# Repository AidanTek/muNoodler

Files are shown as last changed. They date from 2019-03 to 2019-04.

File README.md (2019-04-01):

# µNoodler Project
## Technical Files and Info for the µNoodler SAMD21G18A breakout

This project is for me to learn about a number of things, the idea being to build a SAMD21G18A MCU breakout from the ground up that can be used for Circuit Python, MicroPython or Arduino programming. You are welcome to use the files here for anything you want. 

This project was and is possible because of the amazing contributions towards OSH from Adafruit and Arduino - in support, please buy genuine products from these companies!

This is a work in progress! Aidan Taylor 2019

See the installation guide if you have a muNoodler board to experiment with. The Sketch directory provides code examples - contributions are welcome!

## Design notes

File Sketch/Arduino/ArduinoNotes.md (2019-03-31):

# Notes on using the Arduino IDE with the µNoodler

## Native Usb

To send data over serial back to a computer, use the SerialUSB object in place of Serial. For example:

```cpp
SerialUSB.begin(115200);
SerialUSB.println("Hello World!");
```

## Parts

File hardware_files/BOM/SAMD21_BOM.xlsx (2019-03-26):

Qty | Value | Device | Package | Parts | Description | AVAILABILITY | DESCRIPTION | MF | MP | PACKAGE | PRICE | PROD_ID | SPICEPREFIX | VALUE
1 |  | CONN_08";1X08" | J1 | Multi connection point. Often used as Generic Header-pin footprint for 0.1 inch spaced/style header connections |  |  |  |  |  |  | CONN-08438
2 |  | LED0603 | LED-0603 | D1, D2 | LED (Generic)
2 |  | R-EU_R0603 | R0603 | R1, R2 | RESISTOR, European symbol |  |  |  |  |  |  |  | R
4 | 0.1uf | C-EUC0603 | C0603 | C3, C4, C5, C7 | CAPACITOR, European symbol |  |  |  |  |  |  |  | C
1 | 10118193-0001LF | 10118193-0001LF | FCI_10118193-0001LF | P1 | Micro USB B Type Receptacle | Unavailable | Conn Micro USB Type B RCP 5 POS 0.65mm Solder RA SMD 5 Terminal 1 Port T/R | Amphenol FCI | 10118193-0001LF | None | None
2 | 10uf | C-EUC0805 | C0805 | C2, C8 | CAPACITOR, European symbol |  |  |  |  |  |  |  | C
1 | 120 | FERRITE_BEAD-0603 | 603 | FB1 | Ferrite Bead (blocks, cores, rings, chokes, etc.) |  |  |  |  |  |  | NDUC-13805 |  | 30Œ©/1.8A
2 | 15pf | C-EUC0603 | C0603 | C9, C10 | CAPACITOR, European symbol |  |  |  |  |  |  |  | C
2 | 1uf | C-EUC0805 | C0805 | C1, C6 | CAPACITOR, European symbol |  |  |  |  |  |  |  | C
1 | 32.768kHz | CRYSTAL-32.768KHZSMD-3.2X1.5 | CRYSTAL-SMD-3.2X1.5MM | Y1 | 32.768kHz Crystal |  |  |  |  |  |  | XTAL-13062 |  | 32.768kHz
1 | ATSAMD21G-A | ATSAMD21G-A | TQFP-48 | U1 | Atmel SAMD21G SMART ARM-Based Microcontroller |  |  |  |  |  |  | IC-13064
2 | HEADER_16X1 | HEADER_16X1 | HDRV16W64P254_1X16_4064X254X900B_NO_SILK | U$1, U$2
1 | KXT3_LOWPROFILE_SMDSWITCH | KXT3_LOWPROFILE_SMDSWITCH | KXT3_SMD_SWITCH | SW1
1 | TLV1117LV33DCYT | TLV1117LV33DCYT | SOT223 | REG1

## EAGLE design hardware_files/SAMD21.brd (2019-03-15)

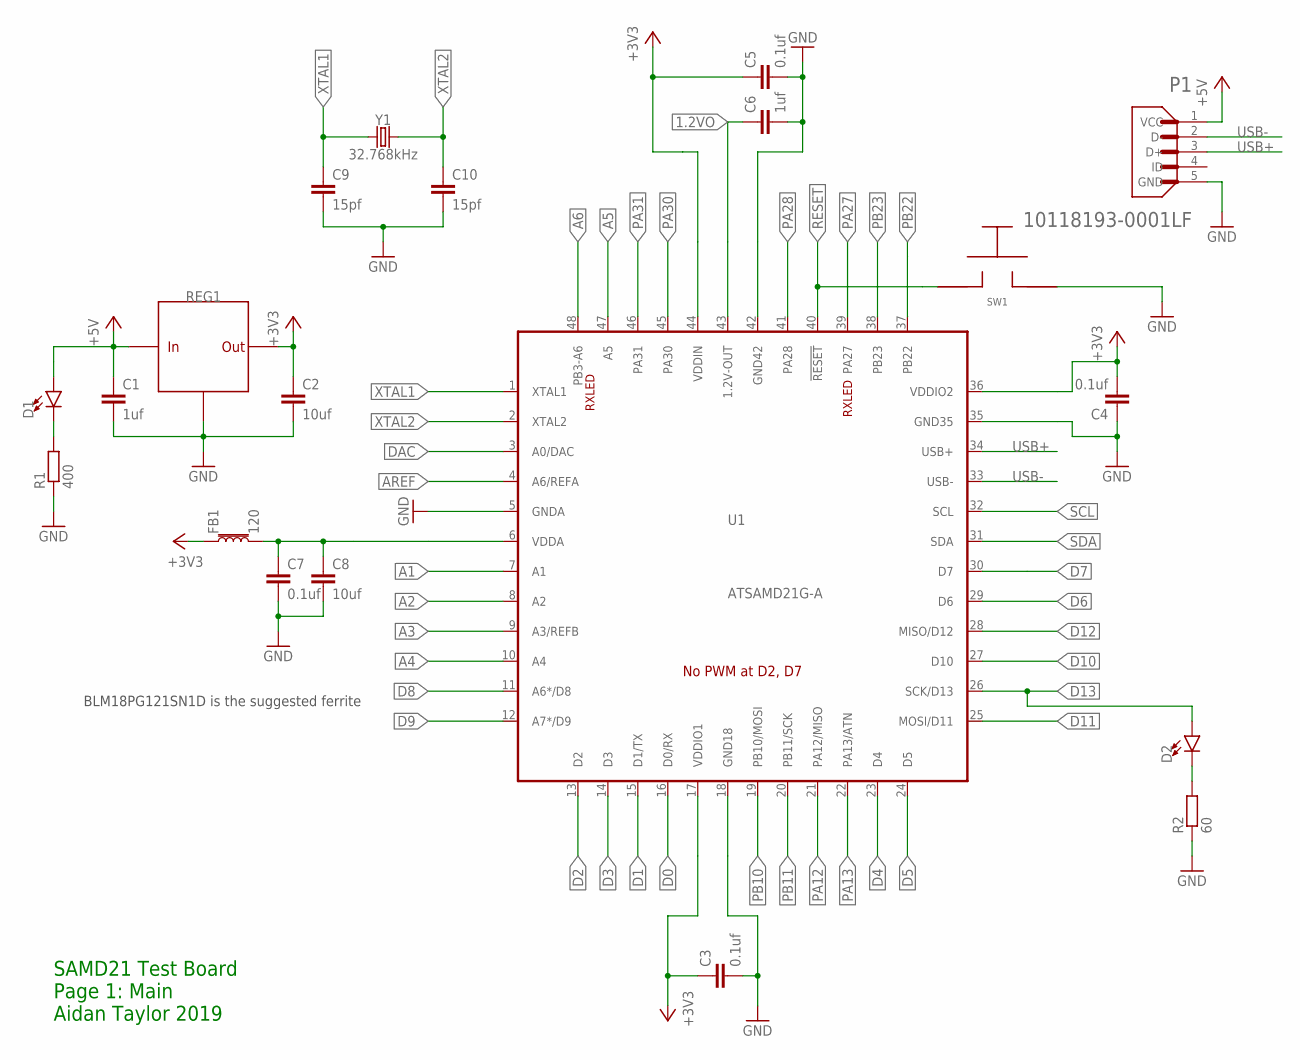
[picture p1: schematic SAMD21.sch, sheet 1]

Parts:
C1, C6: 1uf; C0805
C2, C8: 10uf; C0805
C3, C4, C5, C7: 0.1uf; C0603
C9, C10: 15pf; C0603
D1, D2: LED0603; LED-0603
FB1: 120; 0603
P1: 10118193-0001LF; FCI_10118193-0001LF
R1: 400; R0603
R2: 60; R0603
REG1: TLV1117LV33DCYT; SOT223
SW1: KXT3_LOWPROFILE_SMDSWITCH; KXT3_SMD_SWITCH
U1: ATSAMD21G-A; TQFP-48
Y1: 32.768kHz; CRYSTAL-SMD-3.2X1.5MM

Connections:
1.2VO: C6.1, U1.43 (1.2V-OUT); also elsewhere on the board
+3V3: C2.1, C3.1, C4.2, C5.1, FB1.1, REG1.2 (VOUT), REG1.4 (VOUT), U1.17 (VDDIO1), U1.36 (VDDIO2), U1.44 (VDDIN); also elsewhere on the board
+5V: C1.1, D1.A, P1.1 (VCC), REG1.3 (VIN); also elsewhere on the board
A1: U1.7 (A1); also elsewhere on the board
A2: U1.8 (A2); also elsewhere on the board
A3: U1.9 (A3/REFB); also elsewhere on the board
A4: U1.10 (A4); also elsewhere on the board
A5: U1.47 (A5); also elsewhere on the board
A6: U1.48 (PB3-A6); also elsewhere on the board
AREF: U1.4 (A6/REFA); also elsewhere on the board
D0: U1.16 (D0/RX); also elsewhere on the board
D1: U1.15 (D1/TX); also elsewhere on the board
D2: U1.13 (D2); also elsewhere on the board
D3: U1.14 (D3); also elsewhere on the board
D4: U1.23 (D4); also elsewhere on the board
D5: U1.24 (D5); also elsewhere on the board
D6: U1.29 (D6); also elsewhere on the board
D7: U1.30 (D7); also elsewhere on the board
D8: U1.11 (A6*/D8); also elsewhere on the board
D9: U1.12 (A7*/D9); also elsewhere on the board
D10: U1.27 (D10); also elsewhere on the board
D11: U1.25 (MOSI/D11); also elsewhere on the board
D12: U1.28 (MISO/D12); also elsewhere on the board
D13: D2.A, U1.26 (SCK/D13); also elsewhere on the board
DAC: U1.3 (A0/DAC); also elsewhere on the board
GND: C1.2, C2.2, C3.2, C4.1, C5.2, C6.2, C7.2, C8.2, C9.2, C10.2, P1.5 (GND), R1.1, R2.1, REG1.1 (GND), SW1.P$2, U1.5 (GNDA), U1.18 (GND18), U1.35 (GND35), U1.42 (GND42); also elsewhere on the board
unnamed: C7.1, C8.1, FB1.2, U1.6 (VDDA)
unnamed: D1.C, R1.2
unnamed: D2.C, R2.2
PA12: U1.21 (PA12/MISO); also elsewhere on the board
PA13: U1.22 (PA13/ATN); also elsewhere on the board
PA27: U1.39 (PA27)
PA28: U1.41 (PA28)
PA30: U1.45 (PA30); also elsewhere on the board
PA31: U1.46 (PA31); also elsewhere on the board
PB10: U1.19 (PB10/MOSI); also elsewhere on the board
PB11: U1.20 (PB11/SCK); also elsewhere on the board
PB22: U1.37 (PB22); also elsewhere on the board
PB23: U1.38 (PB23); also elsewhere on the board
RESET: SW1.P$1, U1.40 (!RESET!); also elsewhere on the board
SCL: U1.32 (SCL); also elsewhere on the board
SDA: U1.31 (SDA); also elsewhere on the board
USB+: P1.3 (D+), U1.34 (USB+)
USB-: P1.2 (D-), U1.33 (USB-)
XTAL1: C9.1, U1.1 (XTAL1), Y1.P$1 (1)
XTAL2: C10.1, U1.2 (XTAL2), Y1.P$2 (2)

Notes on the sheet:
BLM18PG121SN1D is the suggested ferrite
SAMD21 Test Board Page 1: Main Aidan Taylor 2019

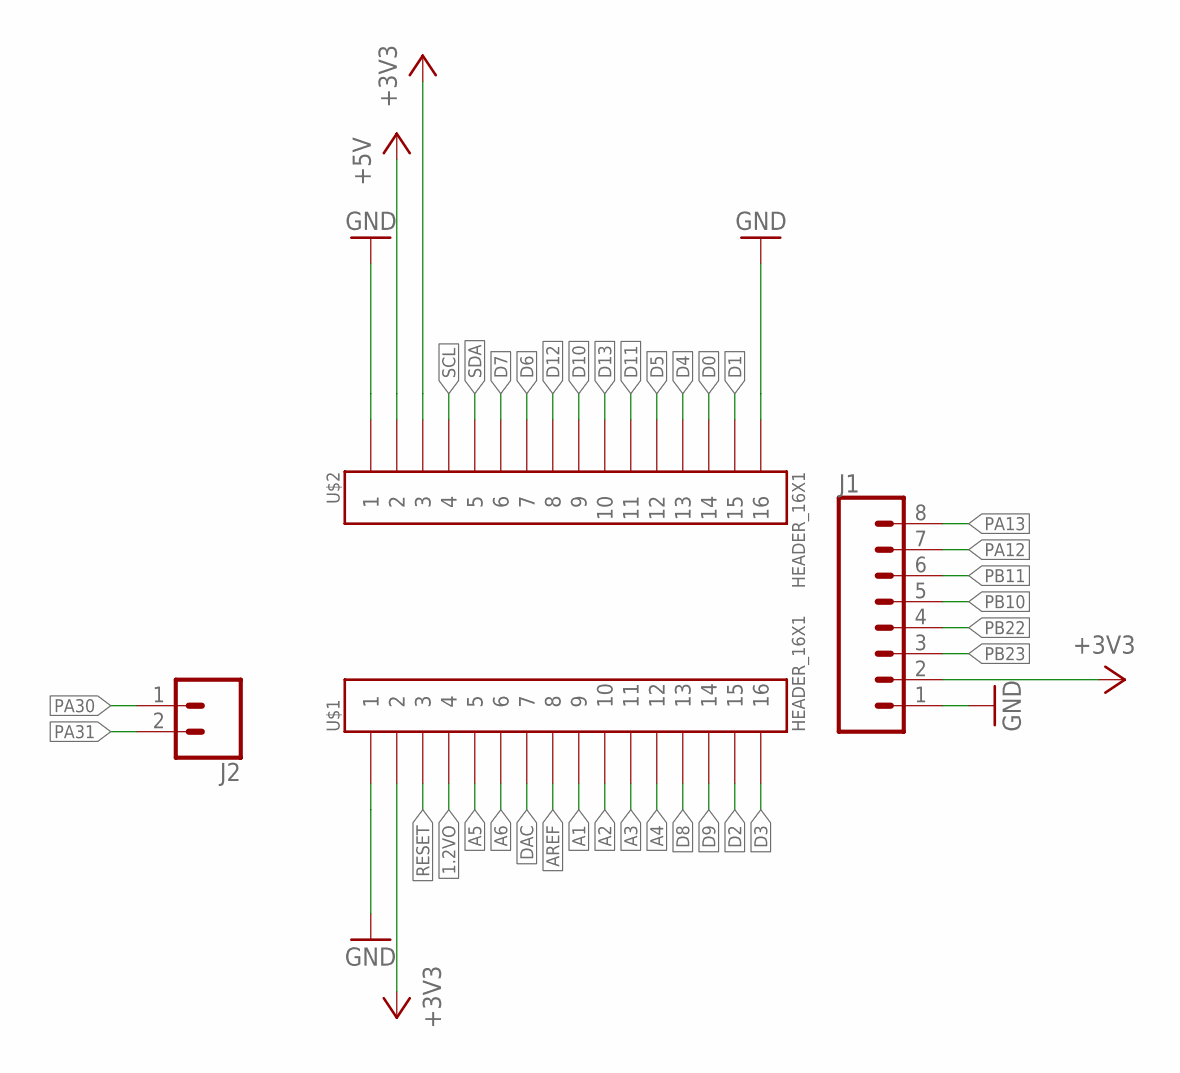
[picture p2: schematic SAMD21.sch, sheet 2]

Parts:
J1: CONN_08"; 1X08
J2: CONN_02; 1X02
U$1, U$2: HEADER_16X1; HDRV16W64P254_1X16_4064X254X900B_NO_SILK

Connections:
1.2VO: U$1.P$4 (4); also elsewhere on the board
+3V3: J1.2, U$1.P$2 (2), U$2.P$3 (3); also elsewhere on the board
+5V: U$2.P$2 (2); also elsewhere on the board
A1: U$1.P$9 (9); also elsewhere on the board
A2: U$1.P$10 (10); also elsewhere on the board
A3: U$1.P$11 (11); also elsewhere on the board
A4: U$1.P$12 (12); also elsewhere on the board
A5: U$1.P$5 (5); also elsewhere on the board
A6: U$1.P$6 (6); also elsewhere on the board
AREF: U$1.P$8 (8); also elsewhere on the board
D0: U$2.P$14 (14); also elsewhere on the board
D1: U$2.P$15 (15); also elsewhere on the board
D2: U$1.P$15 (15); also elsewhere on the board
D3: U$1.P$16 (16); also elsewhere on the board
D4: U$2.P$13 (13); also elsewhere on the board
D5: U$2.P$12 (12); also elsewhere on the board
D6: U$2.P$7 (7); also elsewhere on the board
D7: U$2.P$6 (6); also elsewhere on the board
D8: U$1.P$13 (13); also elsewhere on the board
D9: U$1.P$14 (14); also elsewhere on the board
D10: U$2.P$9 (9); also elsewhere on the board
D11: U$2.P$11 (11); also elsewhere on the board
D12: U$2.P$8 (8); also elsewhere on the board
D13: U$2.P$10 (10); also elsewhere on the board
DAC: U$1.P$7 (7); also elsewhere on the board
GND: J1.1, U$1.P$1 (1), U$2.P$1 (1), U$2.P$16 (16); also elsewhere on the board
PA12: J1.7; also elsewhere on the board
PA13: J1.8; also elsewhere on the board
PA30: J2.1; also elsewhere on the board
PA31: J2.2; also elsewhere on the board
PB10: J1.5; also elsewhere on the board
PB11: J1.6; also elsewhere on the board
PB22: J1.4; also elsewhere on the board
PB23: J1.3; also elsewhere on the board
RESET: U$1.P$3 (3); also elsewhere on the board
SCL: U$2.P$4 (4); also elsewhere on the board
SDA: U$2.P$5 (5); also elsewhere on the board

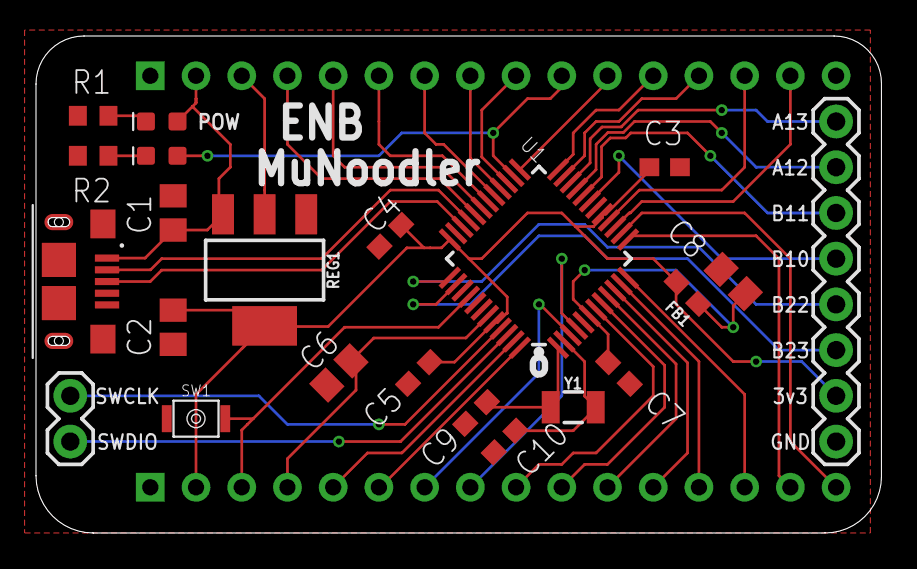
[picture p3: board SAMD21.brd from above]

Board: 2 copper layers, 47.0 x 27.6 mm, 24 parts (0 on the bottom side), 44 nets.

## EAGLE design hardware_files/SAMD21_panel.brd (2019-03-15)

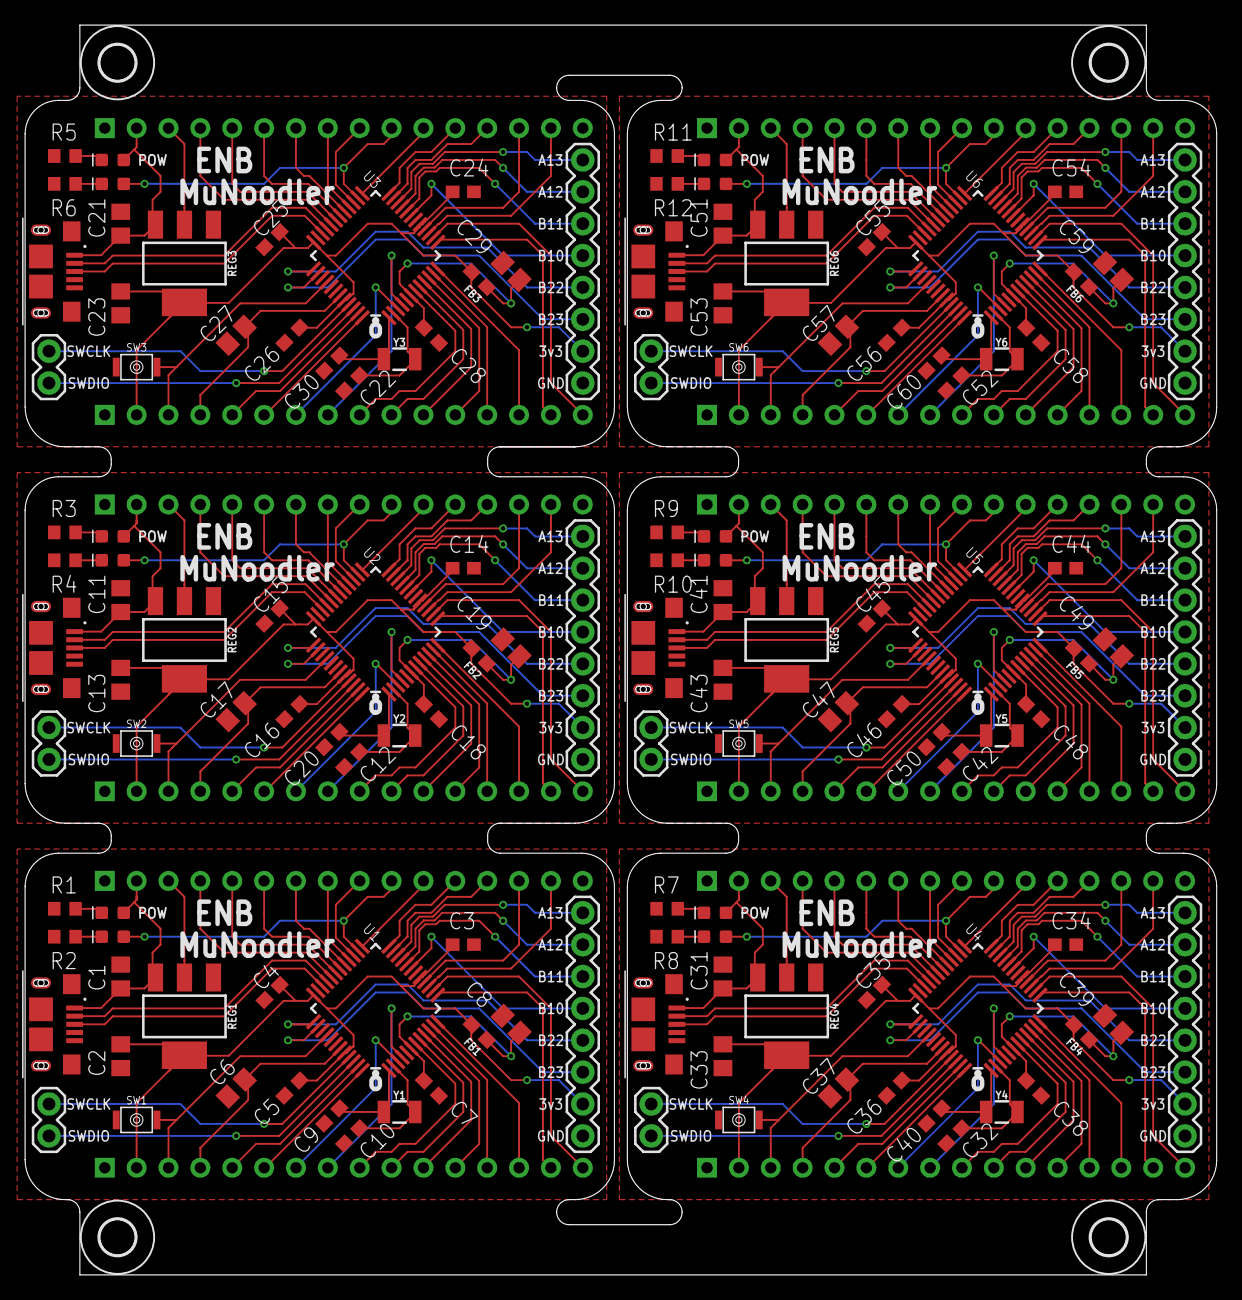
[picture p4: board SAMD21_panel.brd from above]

Board: 2 copper layers, 95.0 x 99.6 mm, 148 parts (0 on the bottom side), 264 nets.

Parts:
C1, C6, C11, C17, C21, C27, C31, C37, C41, C47, C51, C57: 1uf; C0805
C2, C8, C13, C19, C23, C29, C33, C39, C43, C49, C53, C59: 10uf; C0805
C3, C4, C5, C7, C14, C15, C16, C18, C24, C25, C26, C28, C34, C35, C36, C38, C44, C45, C46, C48, C54, C55, C56, C58: 0.1uf; C0603
C9, C10, C12, C20, C22, C30, C32, C40, C42, C50, C52, C60: 15pf; C0603
D1, D2, D3, D4, D5, D6, D7, D8, D9, D10, D11, D12: LED-0603
E$1, E$2, E$3, E$4: 2,8
FB1, FB2, FB3, FB4, FB5, FB6: 120; 0603
J1, J3, J5, J7, J9, J11: 1X08
J2, J4, J6, J8, J10, J12: 1X02
P1, P2, P3, P4, P5, P6: 10118193-0001LF; FCI_10118193-0001LF
R1, R3, R5, R7, R9, R11: 400; R0603
R2, R4, R6, R8, R10, R12: 60; R0603
REG1, REG2, REG3, REG4, REG5, REG6: TLV1117LV33DCYT; SOT223
SW1, SW2, SW3, SW4, SW5, SW6: KXT3_LOWPROFILE_SMDSWITCH; KXT3_SMD_SWITCH
U1, U2, U3, U4, U5, U6: ATSAMD21G-A; TQFP-48
U$1, U$2, U$3, U$4, U$5, U$6, U$7, U$8, U$9, U$10, U$11, U$12: HEADER_16X1; HDRV16W64P254_1X16_4064X254X900B_NO_SILK
Y1, Y2, Y3, Y4, Y5, Y6: 32.768kHz; CRYSTAL-SMD-3.2X1.5MM

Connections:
1.2VO: C6.1, U1.43, U$1.P$4
1.2VO1: C17.1, U2.43, U$3.P$4
1.2VO2: C27.1, U3.43, U$5.P$4
1.2VO3: C37.1, U4.43, U$7.P$4
1.2VO4: C47.1, U5.43, U$9.P$4
1.2VO5: C57.1, U6.43, U$11.P$4
+3V1: C13.1, C14.1, C15.2, C16.1, FB2.1, J3.2, REG2.2, REG2.4, U2.17, U2.36, U2.44, U$3.P$2, U$4.P$3
+3V2: C23.1, C24.1, C25.2, C26.1, FB3.1, J5.2, REG3.2, REG3.4, U3.17, U3.36, U3.44, U$5.P$2, U$6.P$3
+3V3: C2.1, C3.1, C4.2, C5.1, FB1.1, J1.2, REG1.2, REG1.4, U1.17, U1.36, U1.44, U$1.P$2, U$2.P$3
+3V4: C33.1, C34.1, C35.2, C36.1, FB4.1, J7.2, REG4.2, REG4.4, U4.17, U4.36, U4.44, U$7.P$2, U$8.P$3
+3V5: C43.1, C44.1, C45.2, C46.1, FB5.1, J9.2, REG5.2, REG5.4, U5.17, U5.36, U5.44, U$9.P$2, U$10.P$3
+3V6: C53.1, C54.1, C55.2, C56.1, FB6.1, J11.2, REG6.2, REG6.4, U6.17, U6.36, U6.44, U$11.P$2, U$12.P$3
+5V: C1.1, D1.A, P1.1, REG1.3, U$2.P$2
+5V1: C11.1, D3.A, P2.1, REG2.3, U$4.P$2
+5V2: C21.1, D5.A, P3.1, REG3.3, U$6.P$2
+5V3: C31.1, D7.A, P4.1, REG4.3, U$8.P$2
+5V4: C41.1, D9.A, P5.1, REG5.3, U$10.P$2
+5V5: C51.1, D11.A, P6.1, REG6.3, U$12.P$2
A1: U1.7, U$1.P$9
A2: U1.8, U$1.P$10
A3: U1.9, U$1.P$11
A4: U1.10, U$1.P$12
A5: U1.47, U$1.P$5
A6: U1.48, U$1.P$6
A7: U2.48, U$3.P$6
A8: U2.7, U$3.P$9
A9: U2.8, U$3.P$10
A10: U2.9, U$3.P$11
A11: U2.10, U$3.P$12
A12: U2.47, U$3.P$5
A13: U3.48, U$5.P$6
A14: U3.7, U$5.P$9
A15: U3.8, U$5.P$10
A16: U3.9, U$5.P$11
A17: U3.10, U$5.P$12
A18: U3.47, U$5.P$5
A19: U4.48, U$7.P$6
A20: U4.7, U$7.P$9
A21: U4.8, U$7.P$10
A22: U4.9, U$7.P$11
A23: U4.10, U$7.P$12
A24: U4.47, U$7.P$5
A25: U5.48, U$9.P$6
A26: U5.7, U$9.P$9
A27: U5.8, U$9.P$10
A28: U5.9, U$9.P$11
A29: U5.10, U$9.P$12
A30: U5.47, U$9.P$5
A31: U6.48, U$11.P$6
A32: U6.7, U$11.P$9
A33: U6.8, U$11.P$10
A34: U6.9, U$11.P$11
A35: U6.10, U$11.P$12
A36: U6.47, U$11.P$5
AREF: U1.4, U$1.P$8
AREF1: U2.4, U$3.P$8
AREF2: U3.4, U$5.P$8
AREF3: U4.4, U$7.P$8
AREF4: U5.4, U$9.P$8
AREF5: U6.4, U$11.P$8
D0: U1.16, U$2.P$14
D1: U1.15, U$2.P$15
D2: U1.13, U$1.P$15
D3: U1.14, U$1.P$16
D4: U1.23, U$2.P$13
D5: U1.24, U$2.P$12
D6: U1.29, U$2.P$7
D7: U1.30, U$2.P$6
D8: U1.11, U$1.P$13
D9: U1.12, U$1.P$14
D10: U1.27, U$2.P$9
D11: U1.25, U$2.P$11
D12: U1.28, U$2.P$8
D13: D2.A, U1.26, U$2.P$10
D14: U2.12, U$3.P$14
D15: U2.13, U$3.P$15
D16: U2.14, U$3.P$16
D17: U2.15, U$4.P$15
D18: U2.16, U$4.P$14
D19: U2.23, U$4.P$13
D20: U2.24, U$4.P$12
D21: U2.25, U$4.P$11
D22: D4.A, U2.26, U$4.P$10
D23: U2.27, U$4.P$9
D24: U2.28, U$4.P$8
D25: U2.29, U$4.P$7
D26: U2.30, U$4.P$6
D27: U2.11, U$3.P$13
D28: U3.12, U$5.P$14
D29: U3.13, U$5.P$15
D30: U3.14, U$5.P$16
D31: U3.15, U$6.P$15
D32: U3.16, U$6.P$14
D33: U3.23, U$6.P$13
D34: U3.24, U$6.P$12
D35: U3.25, U$6.P$11
D36: D6.A, U3.26, U$6.P$10
D37: U3.27, U$6.P$9
D38: U3.28, U$6.P$8
D39: U3.29, U$6.P$7
D40: U3.30, U$6.P$6
D41: U3.11, U$5.P$13
D42: U4.12, U$7.P$14
D43: U4.13, U$7.P$15
D44: U4.14, U$7.P$16
D45: U4.15, U$8.P$15
D46: U4.16, U$8.P$14
D47: U4.23, U$8.P$13
D48: U4.24, U$8.P$12
D49: U4.25, U$8.P$11
D50: D8.A, U4.26, U$8.P$10
D51: U4.27, U$8.P$9
D52: U4.28, U$8.P$8
D53: U4.29, U$8.P$7
D54: U4.30, U$8.P$6
D55: U4.11, U$7.P$13
D56: U5.12, U$9.P$14
D57: U5.13, U$9.P$15
D58: U5.14, U$9.P$16
D59: U5.15, U$10.P$15
D60: U5.16, U$10.P$14
D61: U5.23, U$10.P$13
D62: U5.24, U$10.P$12
D63: U5.25, U$10.P$11
D64: D10.A, U5.26, U$10.P$10
D65: U5.27, U$10.P$9
D66: U5.28, U$10.P$8
D67: U5.29, U$10.P$7
D68: U5.30, U$10.P$6
D69: U5.11, U$9.P$13
D70: U6.12, U$11.P$14
D71: U6.13, U$11.P$15
D72: U6.14, U$11.P$16
D73: U6.15, U$12.P$15
D74: U6.16, U$12.P$14
D75: U6.23, U$12.P$13
D76: U6.24, U$12.P$12
D77: U6.25, U$12.P$11
D78: D12.A, U6.26, U$12.P$10
D79: U6.27, U$12.P$9
D80: U6.28, U$12.P$8
D81: U6.29, U$12.P$7
D82: U6.30, U$12.P$6
D83: U6.11, U$11.P$13
DAC: U1.3, U$1.P$7
DAC1: U2.3, U$3.P$7
DAC2: U3.3, U$5.P$7
DAC3: U4.3, U$7.P$7
DAC4: U5.3, U$9.P$7
DAC5: U6.3, U$11.P$7
GND: C1.2, C2.2, C3.2, C4.1, C5.2, C6.2, C7.2, C8.2, C9.2, C10.2, J1.1, P1.5, R1.1, R2.1, REG1.1, SW1.P$2, U1.5, U1.18, U1.35, U1.42, U$1.P$1, U$2.P$1, U$2.P$16
GND1: C11.2, C12.2, C13.2, C14.2, C15.1, C16.2, C17.2, C18.2, C19.2, C20.2, J3.1, P2.5, R3.1, R4.1, REG2.1, SW2.P$2, U2.5, U2.18, U2.35, U2.42, U$3.P$1, U$4.P$1, U$4.P$16
GND2: C21.2, C22.2, C23.2, C24.2, C25.1, C26.2, C27.2, C28.2, C29.2, C30.2, J5.1, P3.5, R5.1, R6.1, REG3.1, SW3.P$2, U3.5, U3.18, U3.35, U3.42, U$5.P$1, U$6.P$1, U$6.P$16
GND3: C31.2, C32.2, C33.2, C34.2, C35.1, C36.2, C37.2, C38.2, C39.2, C40.2, J7.1, P4.5, R7.1, R8.1, REG4.1, SW4.P$2, U4.5, U4.18, U4.35, U4.42, U$7.P$1, U$8.P$1, U$8.P$16
GND4: C41.2, C42.2, C43.2, C44.2, C45.1, C46.2, C47.2, C48.2, C49.2, C50.2, J9.1, P5.5, R9.1, R10.1, REG5.1, SW5.P$2, U5.5, U5.18, U5.35, U5.42, U$9.P$1, U$10.P$1, U$10.P$16
GND5: C51.2, C52.2, C53.2, C54.2, C55.1, C56.2, C57.2, C58.2, C59.2, C60.2, J11.1, P6.5, R11.1, R12.1, REG6.1, SW6.P$2, U6.5, U6.18, U6.35, U6.42, U$11.P$1, U$12.P$1, U$12.P$16
unnamed: C7.1, C8.1, FB1.2, U1.6
unnamed: D1.C, R1.2
unnamed: D2.C, R2.2
unnamed: C18.1, C19.1, FB2.2, U2.6
unnamed: D3.C, R3.2
unnamed: D4.C, R4.2
unnamed: C28.1, C29.1, FB3.2, U3.6
unnamed: D5.C, R5.2
unnamed: D6.C, R6.2
unnamed: C38.1, C39.1, FB4.2, U4.6
unnamed: D7.C, R7.2
unnamed: D8.C, R8.2
unnamed: C48.1, C49.1, FB5.2, U5.6
unnamed: D9.C, R9.2
unnamed: D10.C, R10.2
unnamed: C58.1, C59.1, FB6.2, U6.6
unnamed: D11.C, R11.2
unnamed: D12.C, R12.2
PA1: J3.7, U2.21
PA2: J3.8, U2.22
PA5: J4.1, U2.45
PA6: J4.2, U2.46
PA7: J5.7, U3.21
PA8: J5.8, U3.22
PA11: J6.1, U3.45
PA12: J1.7, U1.21
PA13: J1.8, U1.22
PA14: J6.2, U3.46
PA15: J7.7, U4.21
PA16: J7.8, U4.22
PA19: J8.1, U4.45
PA20: J8.2, U4.46
PA21: J9.7, U5.21
PA22: J9.8, U5.22
PA25: J10.1, U5.45
PA26: J10.2, U5.46
PA29: J11.7, U6.21
PA30: J2.1, U1.45
PA31: J2.2, U1.46
PA32: J11.8, U6.22
PA35: J12.1, U6.45
PA36: J12.2, U6.46
PB1: J3.5, U2.19
PB2: J3.6, U2.20
PB3: J3.4, U2.37
PB4: J3.3, U2.38
PB5: J5.5, U3.19
PB6: J5.6, U3.20
PB7: J5.4, U3.37
PB8: J5.3, U3.38
PB9: J7.5, U4.19
PB10: J1.5, U1.19
PB11: J1.6, U1.20
PB12: J7.6, U4.20
PB13: J7.4, U4.37
PB14: J7.3, U4.38
PB15: J9.5, U5.19
PB16: J9.6, U5.20
PB17: J9.4, U5.37
PB18: J9.3, U5.38
PB19: J11.5, U6.19
PB20: J11.6, U6.20
PB21: J11.4, U6.37
PB22: J1.4, U1.37
PB23: J1.3, U1.38
PB24: J11.3, U6.38
RESET: SW1.P$1, U1.40, U$1.P$3
RESET1: SW2.P$1, U2.40, U$3.P$3
RESET2: SW3.P$1, U3.40, U$5.P$3
RESET3: SW4.P$1, U4.40, U$7.P$3
RESET4: SW5.P$1, U5.40, U$9.P$3
RESET5: SW6.P$1, U6.40, U$11.P$3
SCL: U1.32, U$2.P$4
SCL1: U2.32, U$4.P$4
SCL2: U3.32, U$6.P$4
SCL3: U4.32, U$8.P$4
SCL4: U5.32, U$10.P$4
SCL5: U6.32, U$12.P$4
SDA: U1.31, U$2.P$5
SDA1: U2.31, U$4.P$5
SDA2: U3.31, U$6.P$5
SDA3: U4.31, U$8.P$5
SDA4: U5.31, U$10.P$5
SDA5: U6.31, U$12.P$5
USB+: P1.3, U1.34
USB+1: P2.3, U2.34
USB+2: P3.3, U3.34
USB+3: P4.3, U4.34
USB+4: P5.3, U5.34
USB+5: P6.3, U6.34
USB-: P1.2, U1.33
USB-1: P2.2, U2.33
USB-2: P3.2, U3.33
USB-3: P4.2, U4.33
USB-4: P5.2, U5.33
USB-5: P6.2, U6.33
XTAL1: C9.1, U1.1, Y1.P$1
XTAL2: C10.1, U1.2, Y1.P$2
XTAL3: C20.1, U2.1, Y2.P$1
XTAL4: C12.1, U2.2, Y2.P$2
XTAL5: C30.1, U3.1, Y3.P$1
XTAL6: C22.1, U3.2, Y3.P$2
XTAL7: C40.1, U4.1, Y4.P$1
XTAL8: C32.1, U4.2, Y4.P$2
XTAL9: C50.1, U5.1, Y5.P$1
XTAL10: C42.1, U5.2, Y5.P$2
XTAL11: C60.1, U6.1, Y6.P$1
XTAL12: C52.1, U6.2, Y6.P$2

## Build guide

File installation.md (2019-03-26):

# Installation Guide

## Arduino

The current board bootloader is based on the Arduino/Genuino Zero, I have a modified board installer which can be accessed from this repository, it works but I haven't added the extra pins that I have broken out on my hardware just yet

* Open Arduino
* Open the Preferences 
* In 'Additional Boards Manager URLs' add the following line (if you already have some text in there, put a comma at the end then past it in):

```
https://raw.githubusercontent.com/AidanTek/muNoodler/master/ElectricNoodleBox/package_munoodler_index.json
```

* Now click ok, navigate to **Tools>Board>Boards Manager...**
* Type mu in the search criteria, you should see the Electric Noodle Box board installer pop up - click install

That's it - now you can select the board from the **Tools>Boards>** menu, try uploading blink to the board

# Circuit Python

The board can easily be configured for Circuit Python, guide to follow!

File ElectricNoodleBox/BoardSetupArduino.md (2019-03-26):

# Board Setup step by step

This needs to be improved, some stuff is OS X specific - this is just for my own reference right now, contributions welcome.

1. Copy SAMD/version folder from Arduino15 hardware library
2. Delete unwanted boards from boards.txt and variants
3. Rename lines in boards.txt, change names, change VID and PID - this last bit is not legal for distributed products
4. Change name and version in platform.txt
5. Change PID in USBCore.cpp
6. Rename variants directory
7. Rename top directory and compress
8. Remove the '__MACOSX/' directory with 
```
zip -d your-archive.zip “__MACOSX*”
```
9. Get sha256 checksum with 
```
shasum -a 256 file.zip
```
10. edit json with checksum and zip file size

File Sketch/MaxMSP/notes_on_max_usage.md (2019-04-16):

# Notes on Max/MSP usage

## Serial Connection

I haven't found a fool proof way of getting a serial port to open reliably. YMMV, once you are connected, things tend to work as expected. Some quick notes if you are having problems:

* Unplug and reconnect the USB lead between the computer and µNoodler
* Check the serial port list in Max/MSP
* Edit the serial object (even if you have nothing to change, just editing it seems to update it!)
* Do not open the Serial Monitor in the Arduino IDE until you have covered the previous steps

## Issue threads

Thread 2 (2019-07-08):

Arduino SAMD 1.8.x is not compatible

AidanTek, 2019-07-08:
The latest Arduino core SAMD updates are not compatible, the core needs updating - should aim to not rely on the Arduino core in the future

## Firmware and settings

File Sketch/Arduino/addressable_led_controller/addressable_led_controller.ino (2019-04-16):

/*
 * This is an addressable LED controller designed to
 * work with the Max/MSP MultiSerialOutput sketch
 * 
 * This sketch requires the FastLED.h library which 
 * can be installed from the library manager in the
 * Sketch > Include Library menu
 */

#include <FastLED.h>

const uint8_t totalleds = 8; // How many LEDs are connected
const uint8_t datapin = 9; // Which pin are you connected to?

// Instance of the CRGB class (part of FastLED)
CRGB leds[totalleds];

// A function for updating the LEDs:
void setPixel(uint16_t pixel, uint8_t r, uint8_t g, uint8_t b) {
  leds[pixel].r = r;
  leds[pixel].g = g;
  leds[pixel].b = b;

   FastLED.show();
}

void setup() {
  // Open the native Serial port
  SerialUSB.begin(115200);

  // LED setup function:
  FastLED.addLeds<WS2812, datapin, GRB>(leds, totalleds);
  
}

void loop() {
  static uint8_t red;
  static uint8_t green;
  static uint8_t blue;
  
  // Check for incoming serial messages
  if(SerialUSB.available()) {
    // Write into a variable:
    red = SerialUSB.read();
    green = SerialUSB.read();
    blue = SerialUSB.read();

    // Optionally, print it to the Serial Monitor:
    SerialUSB.print(red); SerialUSB.print(" ");
    SerialUSB.print(green); SerialUSB.print(" ");
    SerialUSB.println(blue);

    // Update the LEDs!
    for(uint16_t n = 0; n < totalleds; n++) {
      setPixel(n, red, green, blue);
    }
  } // End of serial block

}

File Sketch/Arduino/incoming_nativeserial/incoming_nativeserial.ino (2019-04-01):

/*
 * Capture incoming serial messages from a computer
 * over the native serial port
 * 
 * Use SerialUSB in place of Serial
 */

void setup() {
  // Open the native Serial port
  SerialUSB.begin(115200);
  
}

void loop() {
  // Check for incoming serial messages
  if(SerialUSB.available()) {
    // Write into a variable:
    uint16_t value = SerialUSB.read();

    // Print it to the Serial Monitor:
    SerialUSB.println(value);
  } // End of serial block
}

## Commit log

2019-03-15 Eagle project files added
    [SAMD21.brd, SAMD21.csv, SAMD21.sch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]
2019-03-26 Arduino board configuration added
    [SAMD21.brd, SAMD21.csv, SAMD21.sch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]
2019-03-26 updates for online installation to board installer .json
2019-03-26 fix attempt online boards installation
2019-03-26 Change to link for munoodler.zip
    For some reason, Arduino is not happy using the .zip file, link to raw may fix
2019-04-01 MaxMSP addressable LED control examples Added
2019-04-16 Addressable LED MaxMSP Interface added

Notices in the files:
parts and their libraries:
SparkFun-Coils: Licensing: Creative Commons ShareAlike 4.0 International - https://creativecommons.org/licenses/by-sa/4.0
